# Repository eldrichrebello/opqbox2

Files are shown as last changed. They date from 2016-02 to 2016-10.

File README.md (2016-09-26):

# Overview

The mission of the Open Power Quality project is to design and implement open source hardware, software, and data for low cost, crowd-sourced power quality monitoring, storage, and analysis. For more details, please see our [home page](http://openpowerquality.org).

This repository provides the proposed schematics for the second generation Open Power Quality metering device (OPQBox2). 

OPQBox2 is in the final design stage.  We are circulating this design to solicit feedback and make improvements prior to production. We greatly appreciate your willingness to provide us with feedback.

# Goal

The goal of OPQBox is to monitor voltage and frequency and detect departures from nominal levels.  It accomplishes this by sampling the waveform 256 times per cycle, extracting power quality measures (including frequency, RMS voltage, and THD), and then uploading data about these measures to the OPQHub service. 

OPQBox can be configured to send a "heartbeat" message to OPQHub to indicate that it is connected and functioning. This message normally includes low resolution voltage and frequency data.   

When a power quality disturbance is detected by OPQBox, it sends a message to OPQHub that includes high resolution voltage and frequency data. 

We plan for OPQBox timestamp data to be synchronized to within 1 millisecond, though we are currently experimenting to determine the best technique to accomplish this. Synchronization enables data from multiple OPQBoxes to be used to generate a global perspective on the state of the grid.  As a simple example, it can enable users to determine if their event is local to their own residence or instead grid-wide. 

# Operational requirements

The design of OPQBox2 is influenced by our experience with the first generation OPQBox (OPQBox1).  Design information about our first generation hardware is available at the [OPQBox1 repository](https://github.com/openpowerquality/opqbox1). 

We performed a [pilot study of our first generation hardware and software](http://openpowerquality.org/technology/g1-pilot-study.html), and one of the results of this study are the following major enhancements for OPQBox2:

 * **Safety.**  OPQBox2 is meant to bypass power filters and surge protectors. Thus it incorporates extra protection elements to keep the device operating safely during power disruptions. Fuses will disable OPQBox2 in case of a fault. All of the user accesible components are isolated from the mains power.

 * **Satisfy IEEE PQ standards.**  OPQBox2 can be plugged into a standard U.S. two prong outlet with expected power at a frequency of 60 Hz and with a voltage of 120 V. It can operate under a frequency range of 50 Hz to 70 Hz and under a voltage range of 80 Vac to 400 Vac. Sampling is phase locked to the utility frequency. The 16 bit 100KSPS ADC allows for 5mV resolution with over 1024 points per grid cycle. On board ARM floating point DSP is able to perform the IEEE 1159 outlined analysis, as well as user defined code.

 * **Support event recording upon power failure.** OPQBox2 adds a super capacitor circuit designed to provide power during service interuptions. 

* **Connectivity.** OPQBox2 is designed to be the deployed as a part of a distributed real-time power quality monitoring network. As such it offers a large number of interface options, including serial, USB, WIFI and cellular network. The initial development will focus on WIFI, and serial communication.
  
# Changes From OPQBox Version 1

OPQBox2 is a complete redesign from the previous generation. It replaces the voltage sensing transformer with an isolation amplifier. The sampling rate has increased from 4kSPS to up to 100kSPS. In order to keep up with the faster acquisition a dedicated ARM DSP is used to control the sampling and realtime processing. Here is a summary of component changes in OPQBox2:

                | OPQBox1 | OPQBox2
--------------- | ------- | -------
**Voltage sensing/Isolation** | 12V transformer wall plug transformer | Isolation amplifier.
**Power**       | 12V transformer | Isolated 5V AC-DC,  Isolated 5V DC-DC
**ADC**         | 4KSPS 16Bit ADC | 100 KSPS 16Bit ADC
**Processing**  | Raspberry Pi for processing/WiFi | Dedicated ARM DSP for real time processing.
                |         | Raspberry PI for communication and configuration only.
                |         | PI can be replaced with CAN/RF/Ethernet/GSM module

# PSU Design
Main power for the board is provided by the IRM-10-5 module. Hot side is powered via ADUM5010 chipscale isolated DC-DC converter.

ADUM5010 PSU design

Design notes:
  * 2A of power on the isolated side
  * 0.22uF super capacitor.(~1s interruption protection)
  * 250mW of power on the HOT side.
  * 
# Measurement isolation design

capacitive PSU

Design notes:

  * Measurement is isolated via an isolation amplifier: [TI AMC 1100](http://www.ti.com/product/amc1100).
  * 16bit, 100 kSPS differential ADC: [Analog Devices AD7684](http://www.analog.com/en/analog-to-digital-converters/ad-converters/ad7684/products/product.html).
  * Flame proof, pulse withstanding resistors for voltage measurement.
  * Thermal metal oxide varistors for surge protection: 

# Layout

PCB layout is available in the schematics folder. It is provided as a PADs Layout file, as well as gerbers and pdf/image files. This design calls for a 4 layer FR4 board, and measures 100mm by 100mm.  PCB is manufactued and is undergoing testing. This device is intended as an engineering sample. We expect to go through several iterations refining the design. 

### Full Layout

layout

The Isolation barrier is clearly visible. Perhaps a cutout is appropriate to improve isolation?

### Top copper, soldermask, and silkscreen

layout

### Bottom copper, soldermask and silkscreen

layout

# Safety

We have domain knowledge in measurement/DSP, but not PSU design and consumer products. From a safety perspective, we have implemented the following:

  * Creepage/Clearance appropriate for mains power.
  * Isolated power and sensing for all user serviceable components.
  * Circuit Protection (MOV, TVC, etc).
  * EMI, fuse, component rating... etc.

# Engineering sample

We recently produced an engineering sample of this design:



# Additional design documents

  * [OPQBOX2 pdf schematic](https://github.com/openpowerquality/opqbox2/blob/master/Schematics/opqbox2_schematic.pdf?raw=true)
  * [Bill of Materials](https://raw.githubusercontent.com/openpowerquality/opqbox2/master/Schematics/BOM.txt)
  * [Mentor graphics PADS schematic of OPQBOX2](https://github.com/openpowerquality/opqbox2/blob/master/Schematics/opqbox2.sch?raw=true)
  * [PADS library](https://github.com/openpowerquality/opqbox2/tree/master/Schematics/Library)

# Summary of questions for review

Here are the issues we are most concerned about.

  * Should we use a cut-out to improve isolation? 
  * Do you have any other recommendations to improve safety?
  * Do you have any other recommendations to improve measurement accuracy, precision, or reliability?
  * Do you have any recommendations for certifications? (UL, IEEE, IEC, etc)
  
If you would like to meet in person or via teleconference to discuss this design, we would be happy to arrange that. If you can reply with comments to johnson@hawaii.edu, that would be great. 

Thanks so much for your time!

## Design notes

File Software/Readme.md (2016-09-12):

##Raspberry Pi firmware for opqbox2.
Directory listing:

- Acquisition : Main data acquisition and local processing. C++
- kernel : Kernel driver for the OPQBOX2. C
- WIFIutill : Python utilities for manipulating RPI wifi. Python
- DSPutill : Utilities for flashing and reseting the DSP. Python
- proto : Google Protobuf implementation of data serialization. Protobuf
- server : Local UI for the OPQBox. Python/bottle
- test : Tests for DSP firmware and software. Python/C/C++

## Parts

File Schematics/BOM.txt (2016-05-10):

|----------------------------------|
|Bill Of Materials for opqbox2.sch on Tue May 10 00:45:54 2016|
|----------------------------------|
|Item|Qty |Reference|Part Name     |
|----+----+---------+--------------|
|1   |2   |H1-2     |4POS_HEADER   |
|2   |1   |PSU2     |ADUM5010ARSZ  |
|3   |1   |U1       |AMC1100       |	8SOIC
|4   |1   |U2       |ARM_JTAG_8_PIN|
|5   |1   |C1       |CAP,100uF     |
|6   |1   |C20      |CAP,22uF/35V  |
|7   |1   |C11      |CAP0402,0.01uF|
|8   |11  |C4 C6 C9 |CAP0402,0.1uF |
|    |    |C13-15   |              |
|    |    |C17      |              |
|    |    |C21-22   |              |
|    |    |C29 C31  |              |
|9   |1   |C18      |CAP0402,330pF |
|10  |2   |C16 C19  |CAP0402,33pF  |
|11  |2   |C7 C10   |CAP0603,0.1uF |
|12  |3   |C5 C8 C30|CAP0603,1uF   |
|13  |2   |C25-26   |CAP0603,4.7u  |
|14  |2   |C2-3     |CAP0805,22uF  |
|15  |2   |C12 C24  |CAP1210,10uF  |
|16  |1   |U7       |FOX924B       |
|17  |1   |F2       |FUSE1206,62mA |	F1450CT-ND
|18  |1   |F1       |FUSE-RSTA1    |
|19  |1   |L2       |INDUCTOR-1210,|
|    |    |         |1uH           |
|20  |1   |PSU1     |IRM-10-5      |	Mouser
|21  |1   |U11      |ISL21010      |
|22  |4   |LED1-3   |LED  0603     |
|    |    |LED_POWER|              |
|23  |1   |PSU3     |LTC3534EGN    |
|24  |1   |D1       |MBR230LSFT1G  |
|25  |1   |U6       |MCP73123-22SI/|
|    |    |         |MF            |
|26  |1   |U5       |MIC842HYC5-TR |
|27  |1   |MOV1     |MOV-B72214S351|	Mouser
|    |    |         |K101          |
|28  |1   |L1       |MPI2520R1-5R6-|
|    |    |         |R,5.6uH       |
|29  |1   |REG1     |REG-AP2120N-3.|
|    |    |         |3TRG1         |
|30  |1   |R17      |RES0402,0     |
|31  |1   |R21      |RES0402,100   |
|32  |1   |R31      |RES0402,100k  |
|33  |2   |R2 R33   |RES0402,10K   |
|34  |3   |R7 R22   |RES0402,10k   |
|    |    |R27      |              |
|35  |1   |R20      |RES0402,15k   |
|36  |1   |R19      |RES0402,160k  |
|37  |1   |R25      |RES0402,160k  |
|38  |1   |R18      |RES0402,220k  |
|39  |1   |R6       |RES0402,30.9k |
|40  |4   |R3 R28-30|RES0402,330   |
|41  |1   |R23      |RES0402,649k  |
|42  |3   |R24 R26  |RES0402,68    |
|    |    |R32      |              |
|43  |1   |R4       |RES-1/2W,1k   |	CMF1.00KHCCT-ND
|44  |1   |R5       |RES-1/2W,1M   |	CMF1.00MHCCT-ND
|45  |1   |PI1      |RPI           |
|46  |1   |Q1       |SI2305CDS     |
|47  |1   |TVS2     |SMBJ7.0A      |
|48  |1   |U3       |STM32F373CCT6 |
|49  |2   |LINE     |A100452CT-ND  |
|    |    |NEUTRAL  |              |
|----------------------------------|

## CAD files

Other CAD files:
Mechanical/opqboxsize.dwg

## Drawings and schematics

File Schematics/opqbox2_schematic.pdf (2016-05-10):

D

6 | 5 | 4 | 3 | 2 | 1

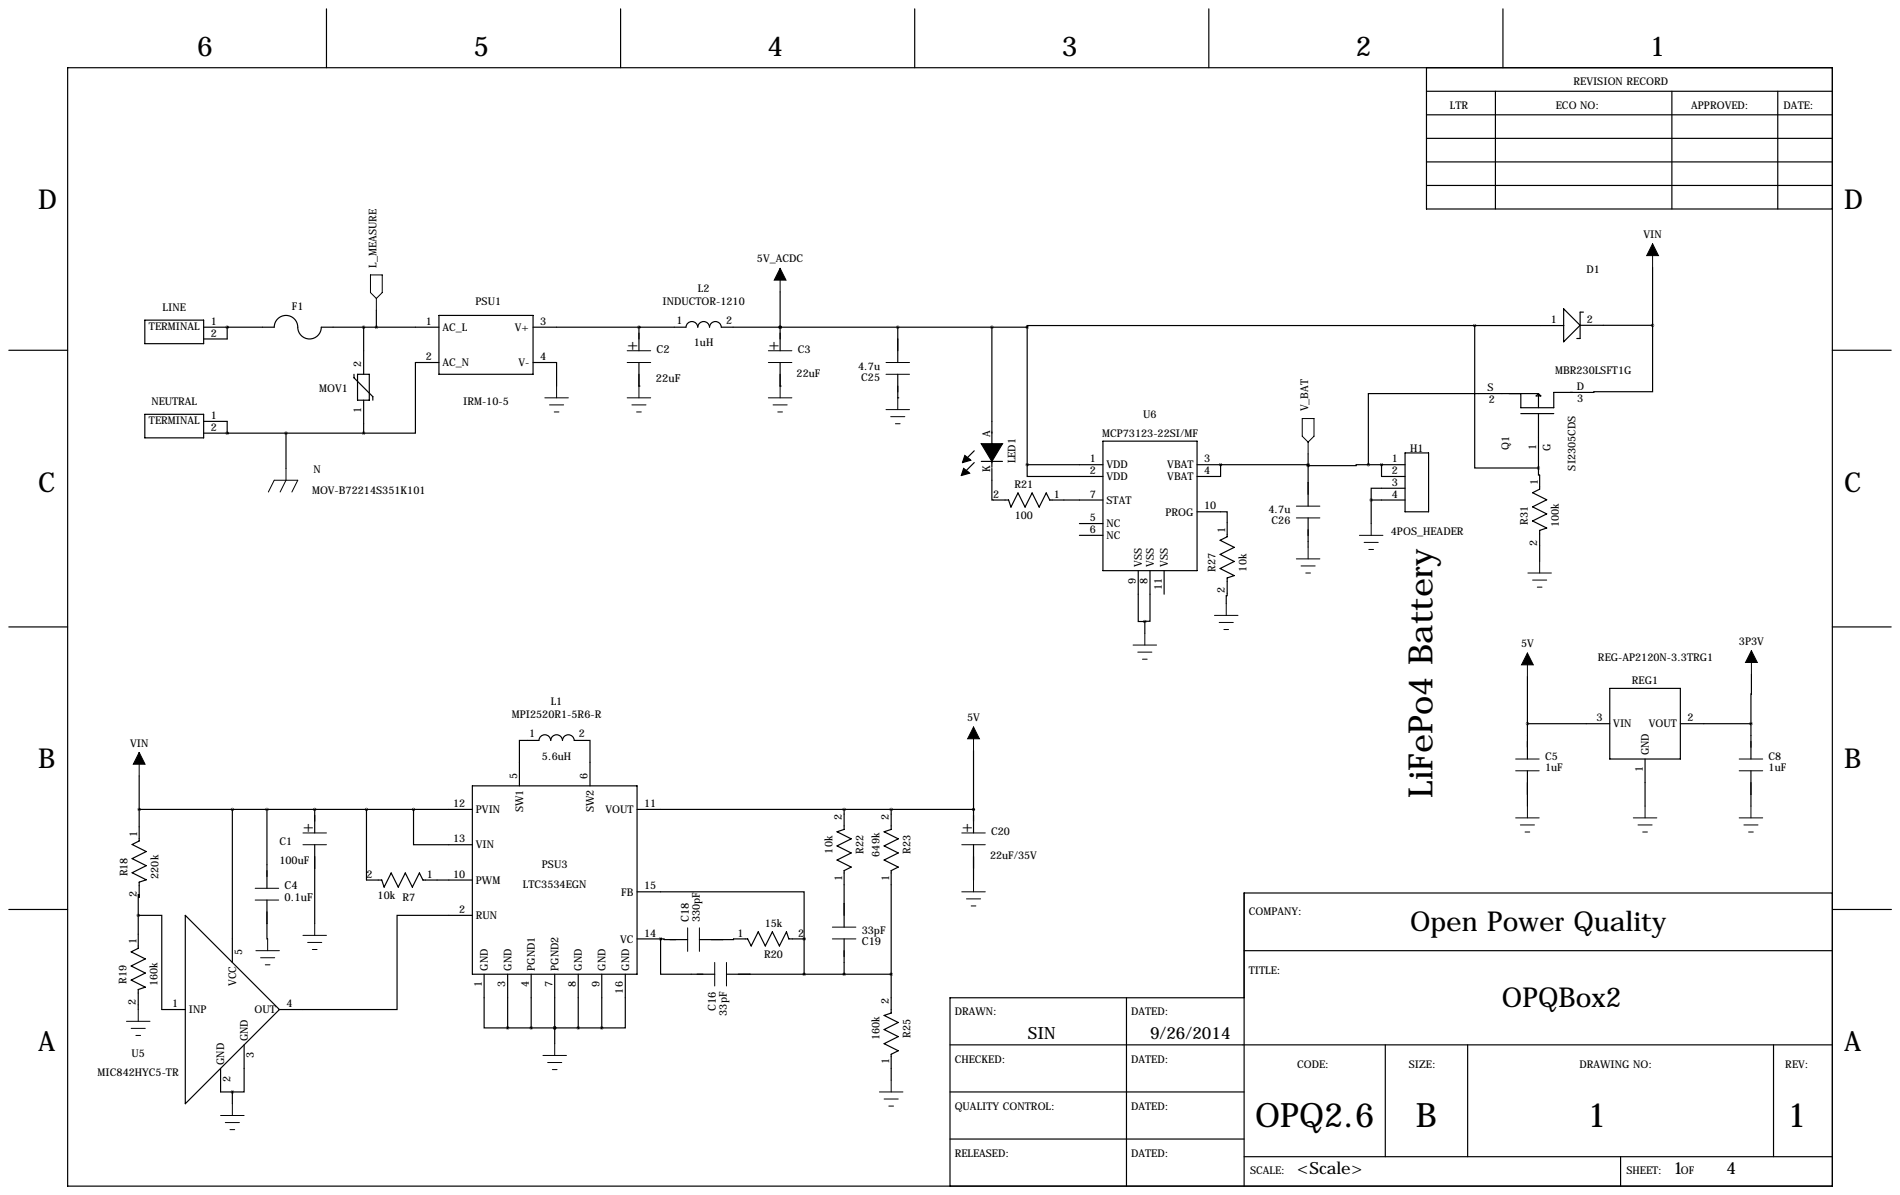
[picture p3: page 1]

REVISION RECORD

LTR | ECO NO: | APPROVED: | DATE:

DRAWN: SIN | DATED: 9/26/2014
CHECKED: | DATED: | CODE: OPQ2.6 | SIZE: B | DRAWING NO: 1 | REV: 1

QUALITY CONTROL: | DATED:

RELEASED: | DATED:

<Scale> SCALE: | 1 4 SHEET: OF

D

D

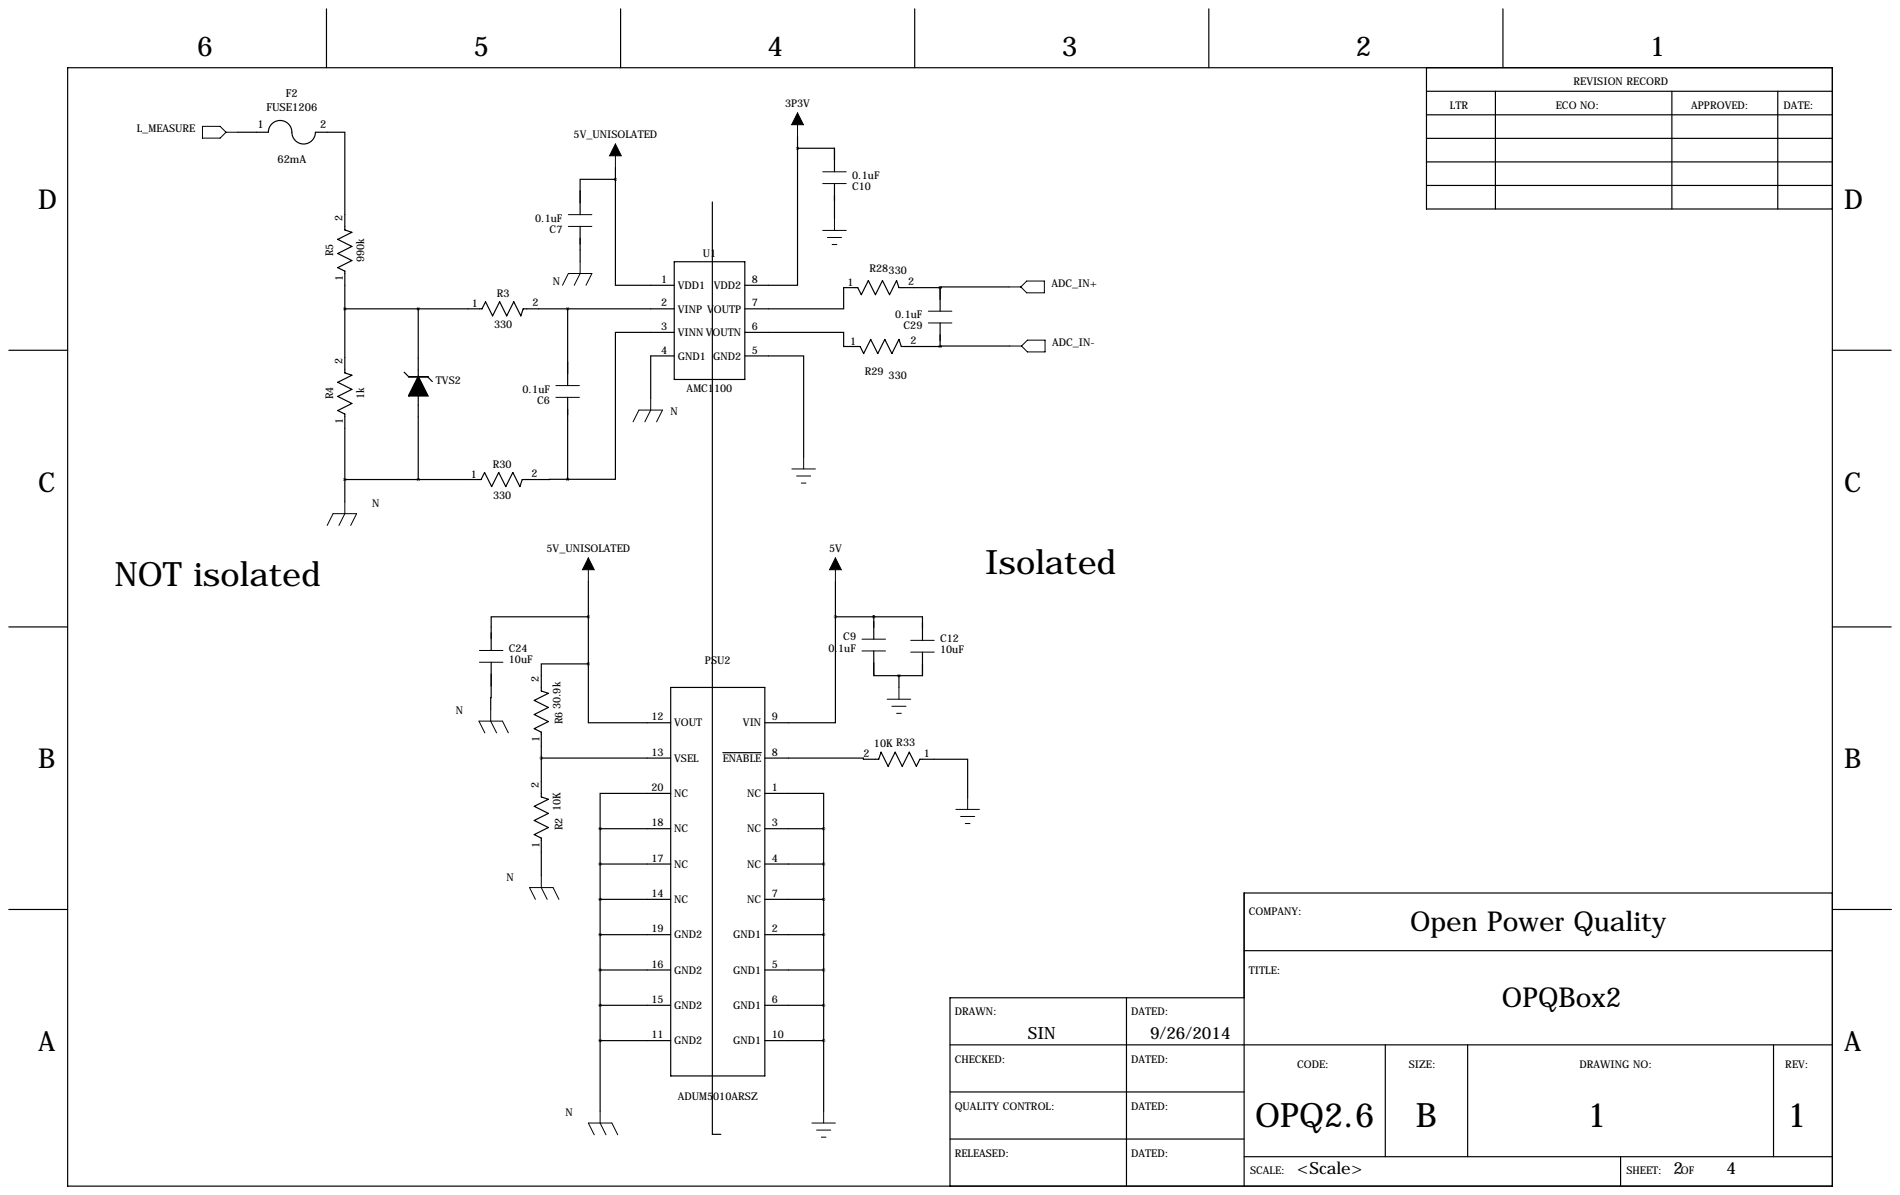
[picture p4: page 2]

3P3V | REVISION RECORD

LTR | ECO NO: | APPROVED: | DATE:

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

QUALITY CONTROL: | DATED:

D

D

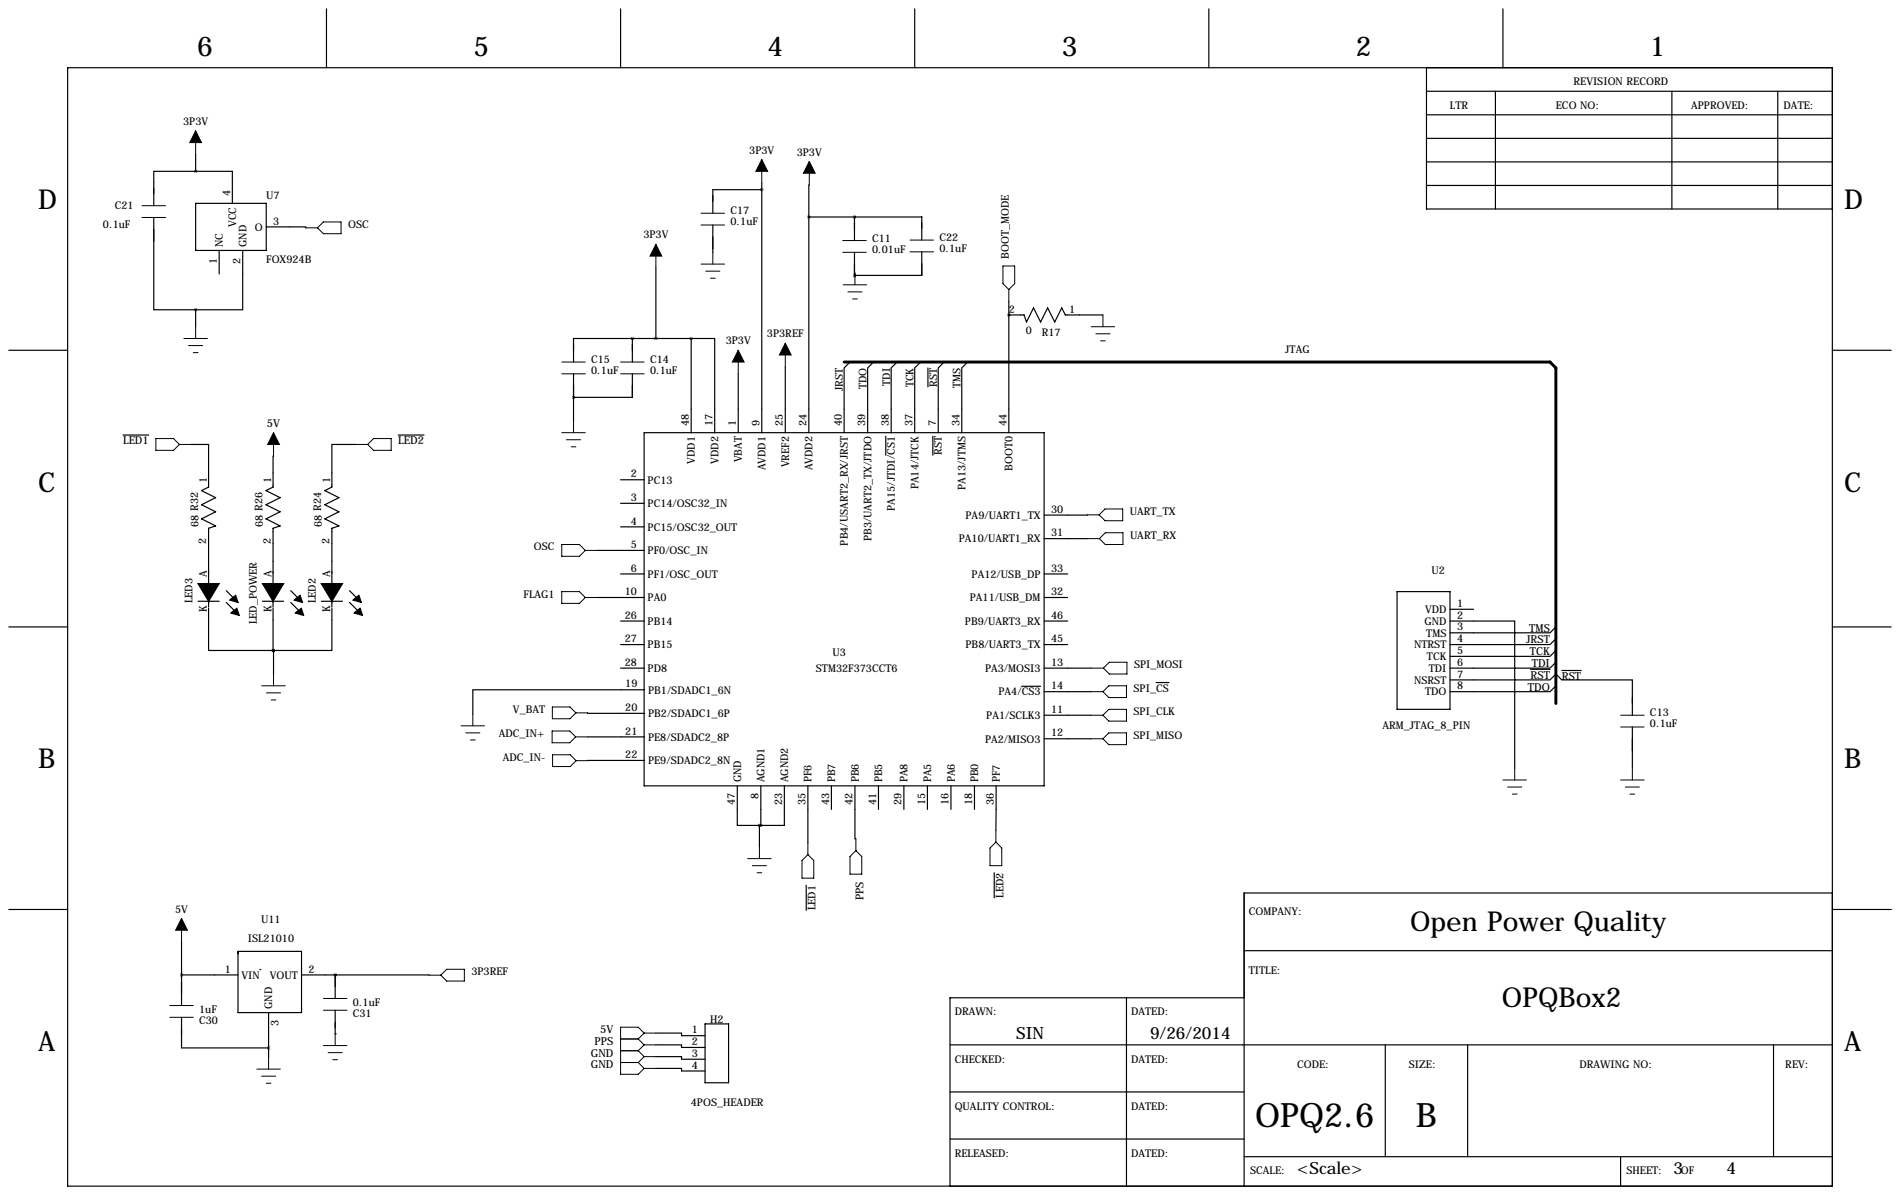
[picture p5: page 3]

3P3V | REVISION RECORD

LTR | ECO NO: | APPROVED: | DATE:

DRAWN: SIN | DATED: 9/26/2014
CHECKED: | DATED: | CODE: OPQ2.6 | SIZE: B | DRAWING NO: | REV:

QUALITY CONTROL: | DATED:

D

D

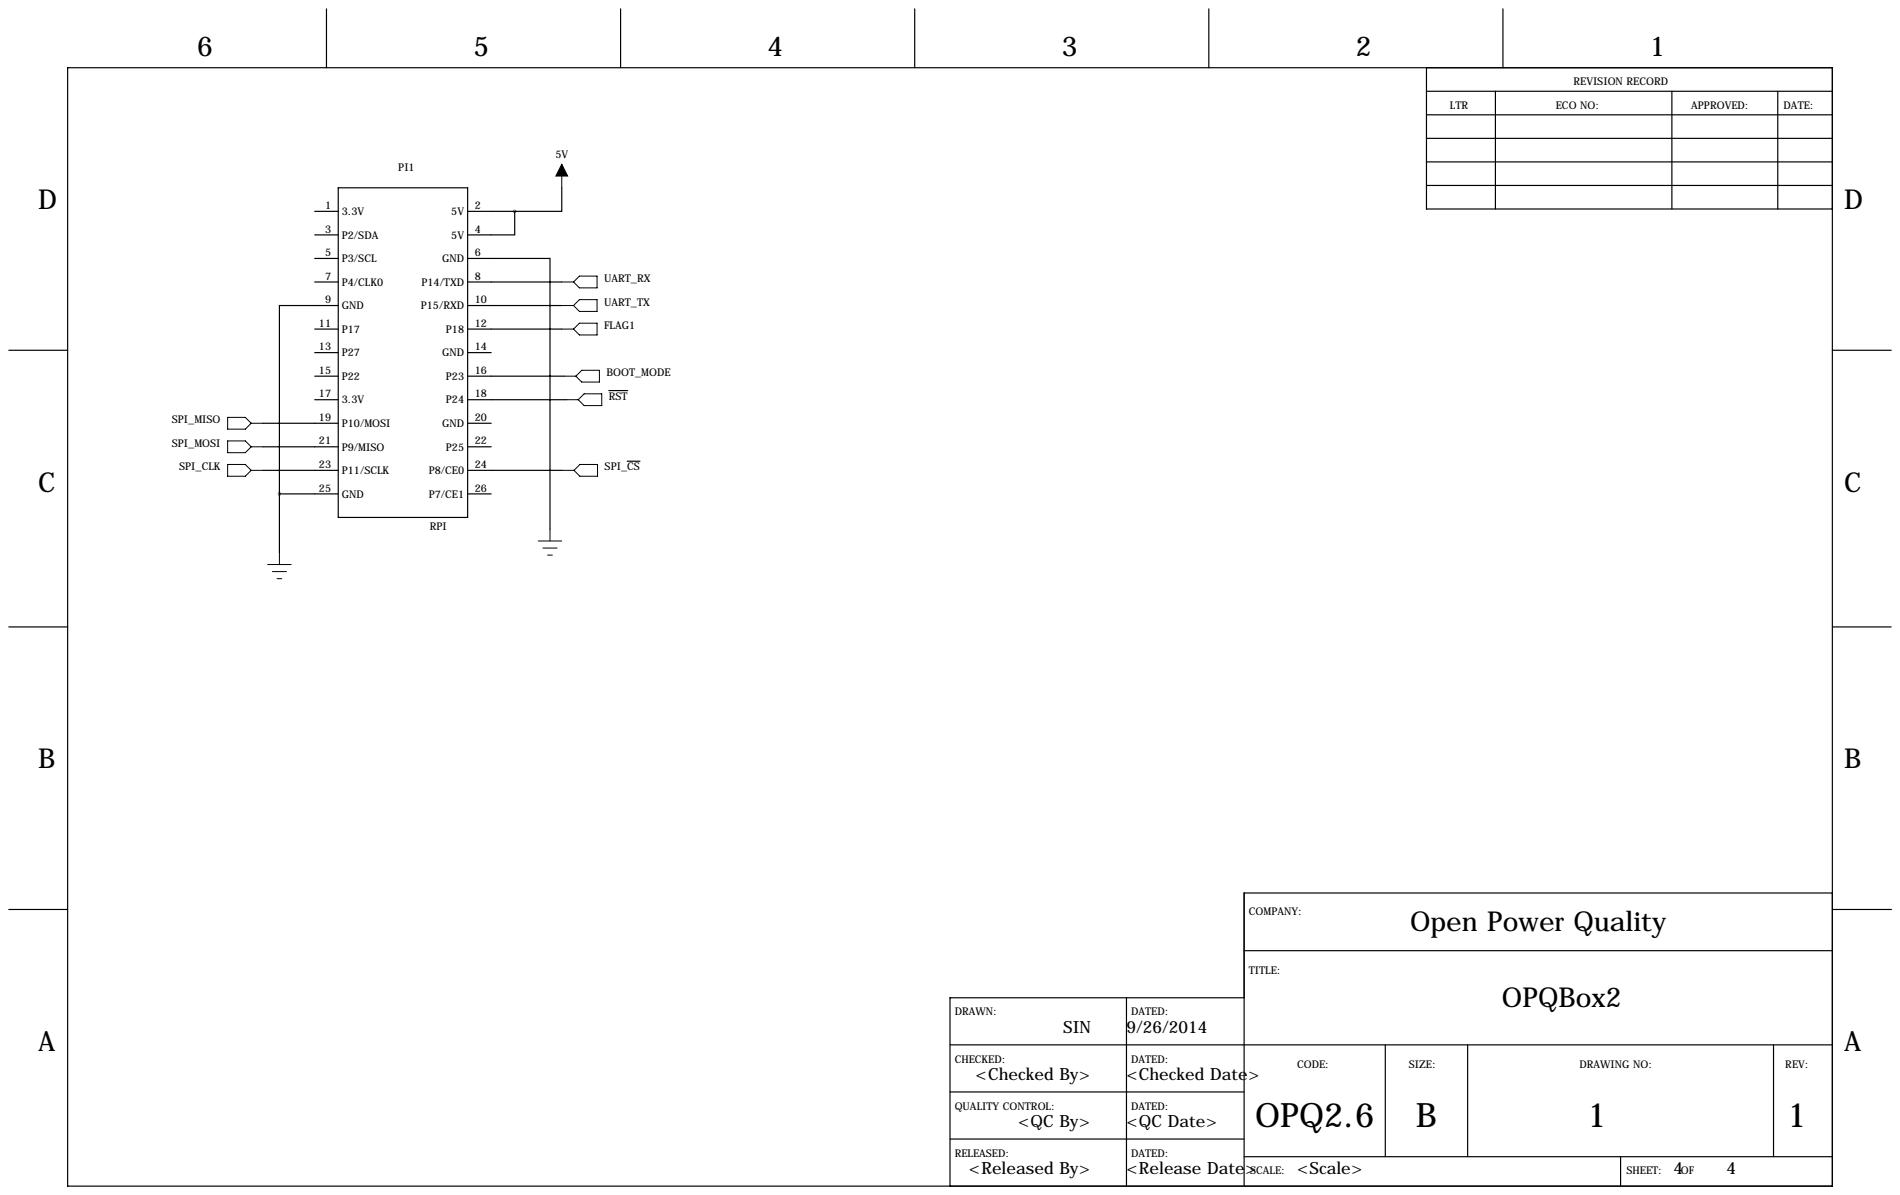
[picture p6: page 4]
<Release Date>; OPQBox2; COMPANY:; TITLE:; P2/SDA; P3/SCL; P4/CLK0; GND; P10/MOSI; P9/MISO; P11/SCLK; P14/TXD; 10 P15/RXD; 14 GND; 20 GND; RPI; UART_RX; UART_TX; FLAG1; SPI_CS; SPI_MISO; SPI_MOSI; SPI_CLK; BOOT_MODE; RST

5V | REVISION RECORD

LTR | ECO NO: | APPROVED: | DATE:

Open Power Quality

DRAWN: SIN | DATED: 9/26/2014
CHECKED: <Checked By> | DATED: <Checked Date> | CODE: OPQ2.6 | SIZE: B | DRAWING NO: 1 | REV: 1

QUALITY CONTROL: <QC By> | DATED: <QC Date>

<Released By>

<Scale> | 4 4

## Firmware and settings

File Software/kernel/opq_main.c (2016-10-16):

#include <linux/module.h>
#include <linux/init.h>
#include <linux/kernel.h>

#include <linux/slab.h>
#include <linux/fs.h>
#include <linux/errno.h>
#include <linux/types.h>
#include <linux/cdev.h>
#include <linux/version.h>
#include <linux/uaccess.h>

#include <linux/interrupt.h>
#include <linux/gpio.h>
#include <linux/spi/spi.h>

#include <linux/workqueue.h>

///GPIO IRQ Stuff stuff:
#define OPQ_DATA_READY_GPIO 18
#define OPQ_DATA_READY_GPIO_DESC           "Data ready pin for the STM32f3"
#define OPQ_DATA_READY_GPIO_DEVICE_DESC    "OPQBox2"
///Character device stuff
#define OPQ_CYCLE_BUFFER_SIZE 408
#define OPQ_CYCLE_BUFFER_COUNT 10
///SPI
#define OPQ_SPI_BUS 0
#define OPQ_SPI_CHAN 0
#define OPQ_SPI_MAX_SPEED 1953000       //mhz ish
#define OPQ_SPI_BITS_PER_WORD 8

struct opq_frame_buffer {
    struct mutex * mutex;
    struct  semaphore* sem;
    uint8_t data[OPQ_CYCLE_BUFFER_COUNT][OPQ_CYCLE_BUFFER_SIZE];
    size_t writer_pos;
    size_t reader_pos;
};

struct opq_device
{
    //serialize access
    struct cdev cdev;
    //SPI Handle
    struct spi_device  * spi_device;
    //Irq number for data ready pin
    short int irq_any_gpio;
    struct workqueue_struct *wq;
    struct opq_frame_buffer *cycles;
    int int_cnt;
};

struct opq_device * opq_dev;

//Chardev
loff_t opq_chardev_lseek(struct file *file, loff_t offset, int orig);
int opq_chardev_open(struct inode *inode,struct file *filep);
int opq_chardev_release(struct inode *inode,struct file *filep);
ssize_t opq_chardev_read(struct file *filep,char *buff,size_t count,loff_t *offp );
ssize_t opq_chardev_write(struct file *filep,const char *buff,size_t count,loff_t *offp );
ssize_t opq_chardev_buffered_read(struct file *filep,char *buff,size_t count,loff_t *offp );
ssize_t opq_chardev_buffered_write(struct file *filep,const char *buff,size_t count,loff_t *offp );
int opq_init_chardev(void);
//GPIO IRQw
static irqreturn_t opq_gpio_irq_handler(int irq, void *dev_id, struct pt_regs *regs);
int opq_gpio_int_config(void);
void opq_gpio_int_release(void);
//SPI
int opq_init_spi(void);
void opq_release_spi(void);
static void opq_wq_spi_reader_handler(struct work_struct *w);
static DECLARE_WORK(opq_wq_spi_reader, opq_wq_spi_reader_handler);
//Buffer
void opq_circ_buffer_init(void);

void opq_circ_buffer_remove(void);


//IRQ Handler
static irqreturn_t opq_gpio_irq_handler(int irq, void *dev_id, struct pt_regs *regs) {
    opq_dev->int_cnt++;
    queue_work(opq_dev->wq, &opq_wq_spi_reader);
    return IRQ_HANDLED;
}

//This will set up the irq
int opq_init_gpio_int(void) {

    if (gpio_request(OPQ_DATA_READY_GPIO, OPQ_DATA_READY_GPIO_DESC)) {
        printk("OPQ: GPIO request faiure: %s\n", OPQ_DATA_READY_GPIO_DESC);
        return -ENODEV;
    }
    if(gpio_direction_input(OPQ_DATA_READY_GPIO)) {
        printk("OPQ: GPIO configuration faiure: %s\n", OPQ_DATA_READY_GPIO_DESC);
        return -ENODEV;
    }
    if ((opq_dev->irq_any_gpio = gpio_to_irq(OPQ_DATA_READY_GPIO)) < 0 ) {
        printk("OPQ: GPIO to IRQ mapping faiure %s\n", OPQ_DATA_READY_GPIO_DESC);
        return-ENODEV;
    }
    opq_dev->wq = create_workqueue("opq_queue");

    if (request_irq(opq_dev->irq_any_gpio,
                    (irq_handler_t ) opq_gpio_irq_handler,
                    IRQF_TRIGGER_RISING,
                    OPQ_DATA_READY_GPIO_DESC,
                    OPQ_DATA_READY_GPIO_DEVICE_DESC)) {
        printk("OPQ: Irq Request failure\n");
        return -ENODEV;
    }
    printk(KERN_NOTICE "OPQ: interrupt %d ready\n", (int)opq_dev->irq_any_gpio);
    return 0;
}

//This will release the IRQ
void opq_release_gpio_int(void) {
    free_irq(opq_dev->irq_any_gpio, OPQ_DATA_READY_GPIO_DEVICE_DESC);
    gpio_free(OPQ_DATA_READY_GPIO);
    cancel_work_sync(&opq_wq_spi_reader);
    destroy_workqueue(opq_dev->wq);
    return;
}

///SPI stuff

int opq_init_spi(void) {
    struct spi_board_info spi_device_info = {
        .modalias = "spi:opq",
        .max_speed_hz = OPQ_SPI_MAX_SPEED,
        .bus_num = OPQ_SPI_BUS,
        .chip_select = OPQ_SPI_CHAN,
        .mode = 0x0,
    };
    int ret;
    struct spi_master *master;
    master = spi_busnum_to_master( spi_device_info.bus_num );
    if( !master ) {
        printk("OPQ: could not allocate SPI master\n");
        return -ENODEV;
    }

    opq_dev->spi_device = spi_new_device( master, &spi_device_info );
    if( !opq_dev->spi_device ) {
        printk("OPQ: could not allocate SPI device\n");
        return -ENODEV;
    }
    opq_dev->spi_device->bits_per_word = OPQ_SPI_BITS_PER_WORD;
    ret = spi_setup( opq_dev->spi_device );
    printk(KERN_NOTICE "OPQ: spi %d:%d ready\n",OPQ_SPI_BUS,OPQ_SPI_CHAN);
    return 0;
}

void opq_release_spi(void) {
    spi_unregister_device( opq_dev->spi_device );
}

//Bottom half og the IRQ Handler
static void opq_wq_spi_reader_handler(struct work_struct *w) {
    mutex_lock(opq_dev->cycles->mutex);
    spi_read(opq_dev->spi_device, opq_dev->cycles->data[opq_dev->cycles->writer_pos], OPQ_CYCLE_BUFFER_SIZE);
    opq_dev->cycles->writer_pos++;
    if(opq_dev->cycles->writer_pos >= OPQ_CYCLE_BUFFER_COUNT)
        opq_dev->cycles->writer_pos  = 0;
    if(opq_dev->cycles->writer_pos  == opq_dev->cycles->reader_pos) {
        //Reader is not keeping up. Have to evict an item.
        //Note we are not touching the semaphore in this case
        //since number of items has not changed.
        opq_dev->cycles->reader_pos++;
        if(opq_dev->cycles->reader_pos >= OPQ_CYCLE_BUFFER_COUNT)
            opq_dev->cycles->reader_pos  = 0;

    }
    else {
        up(opq_dev->cycles->sem);
    }
    mutex_unlock(opq_dev->cycles->mutex);
    //printk("hello\n");
}
//Chardev

static int opq_chardev_major=-1;
static struct file_operations opq_chardev_fops;

int opq_init_chardev()
{
    dev_t tmpchrdev;

    opq_chardev_fops.open =  opq_chardev_open;
    opq_chardev_fops.read = opq_chardev_read;
    opq_chardev_fops.write = opq_chardev_write;
    opq_chardev_fops.release = opq_chardev_release;
    opq_chardev_fops.llseek = opq_chardev_lseek;
    if(alloc_chrdev_region (&tmpchrdev,0,1,"opq_chardev")<0)
    {
        printk("OPQ: couldnt get major/minor number.\n");
        return -1;
    }
    opq_chardev_major=MAJOR(tmpchrdev);
    cdev_init ( &opq_dev->cdev, &opq_chardev_fops);
    opq_dev->cdev.owner = THIS_MODULE;
    opq_dev->cdev.ops = &opq_chardev_fops;
    if(cdev_add(&opq_dev->cdev, MKDEV(opq_chardev_major, 0), 1) < 0)
    {
        printk("OPQ: Failed to initialize character device\n");
        return -1;
    }
    printk("OPQ: Initialized character device with major number %d\n", opq_chardev_major);
    return 0;
}

void opq_release_chardev(void)
{
    cdev_del(&opq_dev->cdev);
    unregister_chrdev_region (MKDEV(opq_chardev_major, 0),1);
}

int opq_chardev_open(struct inode *inode,struct file *filep)
{
    printk(KERN_INFO "OPQ: %d opened the pci driver' chr dev\n", current->pid);
    return 0;
}

int opq_chardev_release(struct inode *inode,struct file *filep)
{
    return 0;
}



ssize_t opq_chardev_read(struct file *filp, char __user *buf, size_t count, loff_t *f_pos)
{
    if (down_interruptible(opq_dev->cycles->sem))
        return -ERESTARTSYS;
    mutex_lock(opq_dev->cycles->mutex);
    if(count > OPQ_CYCLE_BUFFER_SIZE)
        count = OPQ_CYCLE_BUFFER_SIZE;

    //Read SPI here
    if(copy_to_user(buf, opq_dev->cycles->data[opq_dev->cycles->reader_pos], count) != 0)
    {
        printk("KERN_ERROR" "OPQ: copy to user failed\n");
    }
    opq_dev->cycles->reader_pos++;
    if(opq_dev->cycles->reader_pos >= OPQ_CYCLE_BUFFER_COUNT)
        opq_dev->cycles->reader_pos = 0;
    mutex_unlock(opq_dev->cycles->mutex);
    return count;
}


ssize_t opq_chardev_write(struct file *filp, const char __user *buf, size_t count, loff_t *f_pos)
{
    return 0;
}

loff_t opq_chardev_lseek(struct file *file, loff_t offset, int orig)
{
    return 0;
}

//Circular buffer stuff
void opq_circ_buffer_init()
{
    opq_dev->cycles = kmalloc(sizeof(struct opq_frame_buffer), GFP_KERNEL);
    opq_dev->cycles->mutex = kmalloc(sizeof(struct mutex), GFP_KERNEL);
    opq_dev->cycles->sem = kmalloc(sizeof(struct semaphore), GFP_KERNEL);
    mutex_init(opq_dev->cycles->mutex);
    sema_init(opq_dev->cycles->sem, 0);
    opq_dev->cycles->writer_pos = 1;
    opq_dev->cycles->reader_pos = 0;
}

void opq_circ_buffer_remove()
{
    kfree(opq_dev->cycles->mutex);
    kfree(opq_dev->cycles->sem);
    kfree(opq_dev->cycles);
}

static int __init opq_module_init(void)
{
    opq_dev = kmalloc(sizeof(struct opq_device), GFP_KERNEL);
    opq_dev->int_cnt = 0;
    opq_circ_buffer_init();
    opq_init_chardev();
    opq_init_spi();
    opq_init_gpio_int();
    printk (KERN_NOTICE "OPQ: OPQ driver loaded!\n");
    return 0;
}

static void __exit opq_module_exit(void)
{
    opq_release_chardev();
    opq_release_spi();
    opq_release_gpio_int();
    opq_circ_buffer_remove();
    printk (KERN_NOTICE "OPQ: OPQ driver exiting.\n");
    kfree(opq_dev);
    return;
}


module_init(opq_module_init);
module_exit(opq_module_exit);

MODULE_LICENSE("GPL");
MODULE_ALIAS("spi:opq");

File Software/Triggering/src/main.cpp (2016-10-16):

#include <iostream>
#include <csignal>
#include <boost/log/core.hpp>
#include <boost/log/trivial.hpp>
#include <boost/log/expressions.hpp>
#include <boost/log/sinks/text_file_backend.hpp>
#include <boost/log/utility/setup/file.hpp>
#include "boost/log/utility/setup/console.hpp"
#include <boost/log/utility/setup/common_attributes.hpp>
#include <boost/log/sources/severity_logger.hpp>
#include <boost/log/sources/record_ostream.hpp>

#include "ZMQTrigger.hpp"
#include "Reader.hpp"
#include "Settings.hpp"
#include "LocalAnalysis.hpp"
#include "version.hpp"
#include "Pipeline.hpp"

using namespace std;
using namespace opq;
using namespace boost;

namespace logging = boost::log;
namespace src = boost::log::sources;
namespace sinks = boost::log::sinks;
namespace keywords = boost::log::keywords;


namespace
{
    ///Flag used to communicate with the signal handler.
    volatile std::sig_atomic_t gSignalStatus;
}

/**
 * Signal handler for a gracefull exit.
 * @param signum signul number.
 */
void bail_handler( int signum )
{
    BOOST_LOG_TRIVIAL(fatal) << "Triggering: Caught SIGINT. Exiting.";
    cout << "Exiting" << endl;
    gSignalStatus = 0;
}

int main(int argc, char** argv) {
    gSignalStatus = 1;
    https://github.com/openpowerquality/opqbox2.git
    //Enable logging to console while we set up the log.
    logging::core::get()->set_filter(
            logging::trivial::severity >= logging::trivial::info
    );
    logging::add_common_attributes();

    //Load the settings file.
    boost::log::add_console_log(std::cerr, keywords::format = "[%TimeStamp%]: %Message%");

    string setting_file;
    if(argc < 2){
        BOOST_LOG_TRIVIAL(warning) << "Started with no arguments. Attempting to load /etc/opq/settings.set";
        setting_file = "/etc/opq/settings.set";
    } else {
        setting_file = argv[1];
    }

    auto settings = opq::Settings::Instance();
    if(!settings->loadFromFile(setting_file)){
        return 1;
    }

    //Set up the log.
    string logPath = settings->getString("log.trg_path");
    if(logPath == "")
        logPath = "log.txt";

    logging::add_file_log(
            keywords::file_name = logPath,
            keywords::format = "[%TimeStamp%]: %Message%",
            keywords::auto_flush = true,
            keywords::min_free_space = 100 * 1024 * 1024
    );

    BOOST_LOG_TRIVIAL(info) << "Triggering " << opq::OPQ_TRG_MAJOR_VERSION << "." << opq::OPQ_TRG_MINOR_VERSION;

    //Create the queues and threads.
    auto readerQueue = opq::data::make_measurement_queue();
    auto analysisQueue = opq::data::make_analysis_queue();

    pipeline::Slab readerSlab;
    opq::Reader reader(readerQueue);

    pipeline::Slab analysisSlab;
    opq::LocalAnalysis analysis(readerQueue, analysisQueue);

    pipeline::Slab triggerSlab;
    opq::ZMQTrigger trigger(analysisQueue);

    //Start all the threads.
    triggerSlab.start([&trigger](bool &running) {trigger.loop(running);});
    readerSlab.start([&reader](bool &running) {reader.loop(running);});
    analysisSlab.start([&analysis](bool &running) {analysis.loop(running);});
    //Post Signal handler for the interrupt signal
    std::signal(SIGINT, bail_handler);
    //Sleep until we catch a signal.
    while(gSignalStatus != 0){
        sleep(1);
    }
    //stop all the threads.
    triggerSlab.stop();
    analysisSlab.stop();
    readerSlab.stop();
    return 0;
}

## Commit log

2016-02-10 Power Changer. DCDC converter simulation
    [opqbox2.sch]
2016-02-11 Added the buck-boost to the schematics. Started on the battery charger.
    [opqbox2.sch]
2016-02-18 Added the lifepo4 battery charger and headers. Added battery failover circuit.
    [opqbox2.sch]
2016-02-20 Added the OPQBox Box
    [opqboxsize.dwg]
2016-02-24 Cleaned up the schematics. Just have to add an SPI bus between the rPI and the DSP and the schematic is complete. Contemplating using the onboard ADC of the STM32 instead of the external one.
    [opqbox2.sch]
2016-02-29 Removed External ADC. Remote programming of the STM32
    [opqbox2.sch]
2016-03-09 Laying out power
    [opqbox2.sch]
2016-03-10 Layed out most of power. Taking up more space then i would like
2016-03-15 started on power planes layed out. switched the dcdc inductor.
    [opqbox2.sch]
2016-04-13 Changed the 20 pin jtag connector to an 8 pin one
    [opqbox2.sch]
2016-04-18 changer the pi position
    [opqbox2.sch]
2016-04-21 Finished the analog portion, added mounting holes. Needs a couple more tweaks, and we can send to the board house.
    [opqbox2.sch]
2016-05-01 DFM looking really good, 4 clearance errors. Going to start working on the BOM.
    [opqbox2.sch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]
2016-05-07 Uploading gerbers
    [bottom-copper.GBL]
2016-05-10 Updated Bom
    [opqbox2.sch]
2016-05-14 Boardhouse identified some problems in the gerbers. Fixed anular rings
    [bottom-pastemask.GBP, top-pastemask.GTP]
2016-06-05 In system programing and uart code and test fixtures.
    [isp.py, testUart.py]
2016-06-10 Timer2 is configured and set up. Next to convince SDADC2 to get triggered by it
2016-06-11 ADC is now triggered by the timer 2. Next up I think i will be implementing a register map accessible via UART.
2016-06-15 Added the register map for uart access. Switching UART to work in interrupt mode
2016-06-19 We are now sampling into a circular framebuffer. Next up to move the framebuffer over via SPI slave
2016-06-19 SPI 3 is initialized. I realized that I messed up the SPI MISO and MOSI between the STM32 and the pi. This is not a huge deal since the SPI interface is unidirectional in our case.
2016-06-20 python SPI driver
2016-06-22 A very fragile version of the firmware which relies on interrupts for SPI transactions. Still its enough to get the data out of the DSP reliably. Will move to DMA once I verify that the data looks ok
2016-06-26 Moved the acquisition functionality into the kernel. Added a reset DSP script
    [opq_main.c]
2016-06-26 Driver is finished
2016-06-27 install script and init loading
    [config.txt]
2016-09-26 generalized threading
2016-09-28 Python high resolution data manager. Closes openpowerquality/project-planning#11. The acquisition deamon uses an encrypted ZeroMQ socket for transport and protobuf for serialization. Upon recieving a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
2016-10-11 Switched to PUB SUB for the triggering
2016-10-16 Interrupt ordering
2016-10-16 Fixed a showstoper bug in the frequency computation
    [isp.py, opq_main.c]
2016-10-18 Timer default settings
2016-10-19 Timer was not reset
2016-12-03 Set up kernel driver with correct group
2017-01-18 Fixed the gps flag
    [opq.c]
